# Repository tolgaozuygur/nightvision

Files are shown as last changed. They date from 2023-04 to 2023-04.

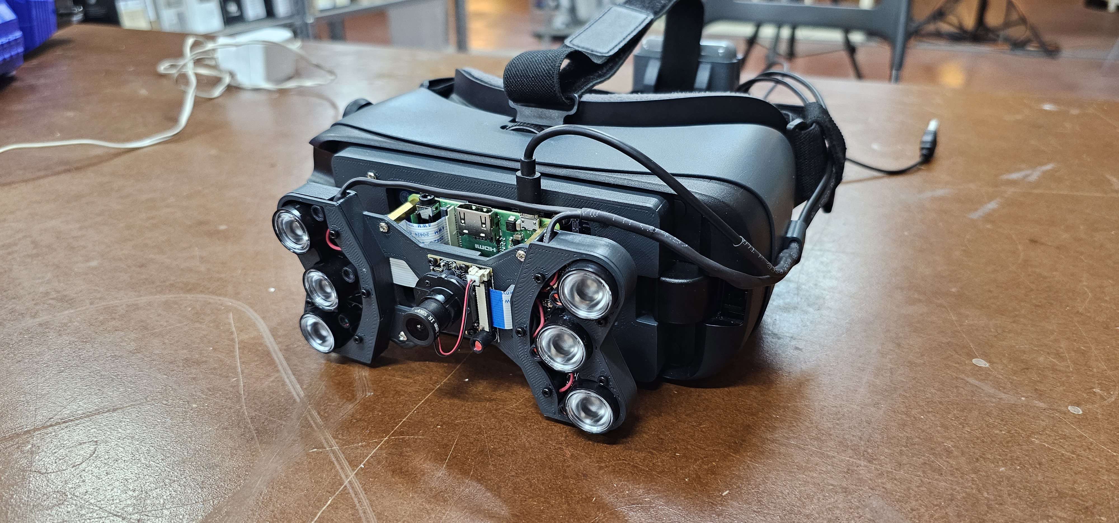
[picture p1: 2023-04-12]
pictures/20230412_170446.jpg

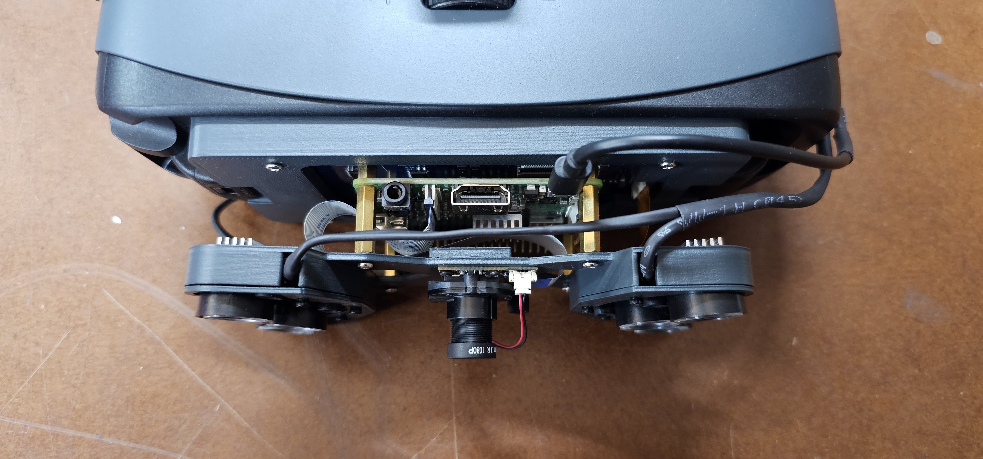
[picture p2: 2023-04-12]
pictures/20230412_170452.jpg

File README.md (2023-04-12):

# Night Vision Goggles
Open source night vision goggles that use old Gear VR headsets as a base. 

## Parts Required / Assembling
- <a href="https://www.raspberrypi.com/products/raspberry-pi-3-model-a-plus/" target="_blank">1x Raspberry Pi 3 A+</a>
- <a href="https://www.waveshare.com/rpi-ir-cut-camera.htm" target="_blank">1x Rpi IR-CUT Camera</a>
- <a href="https://www.waveshare.com/img/devkit/accBoard/Infrared-LED-Board-B/Infrared-LED-Board-B-5.jpg" target="_blank">6x Waveshare IR Led Board</a>
- Samsung Gear VR Headset (You can use any cardboard style headset, but you'll need to modify the 3d files accordingly)
- Powerbank (it should have 2 usb outputs, one should be at least 2A to power the RPI)
- Usb cables, a button switch for function control and RPI shutdown

There are no full instructions yet, but I have added some photos in the /pictures folder to help you assemble the goggles. I also build on my YouTube channel, it is not an instruction video but it might help: https://www.youtube.com/watch?v=c6y9qKiKzgg

## Installation
Copy the nightvision.py to your /pi folder and Run:
``` bash
$ python3 nightvision.py
```
To get it to start when the goggles are booted, follow this guide to add the nightvision.py to LXDE autostart: https://www.raspberrypi-spy.co.uk/2014/05/how-to-autostart-apps-in-rasbian-lxde-desktop/

Note: The script is using MMAL to create multiple images of the camera feed, which is the library for the raspicam. Therefore the script is only tested on Raspberry OS Buster and not Bullseye.

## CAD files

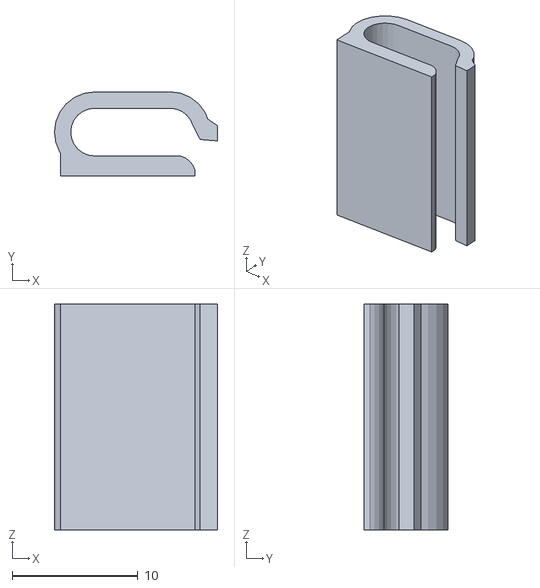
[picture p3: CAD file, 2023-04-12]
3d/nw_cable_clip_x2.stl
13.0 x 6.70 x 18.0

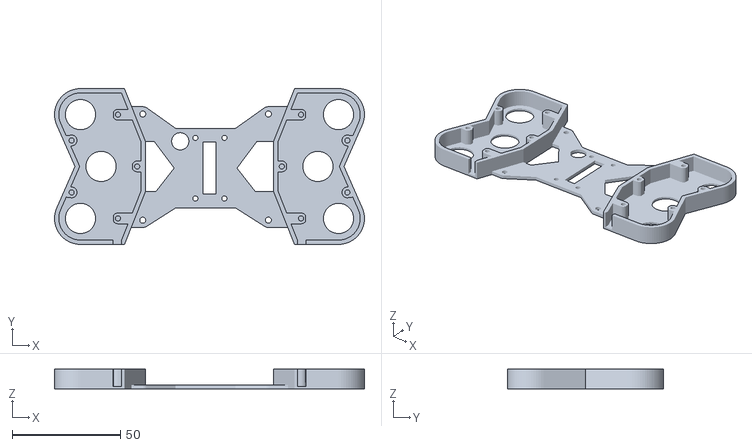
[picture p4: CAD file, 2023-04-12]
3d/nw_cam_holder.stl
143.1 x 72.0 x 9.20

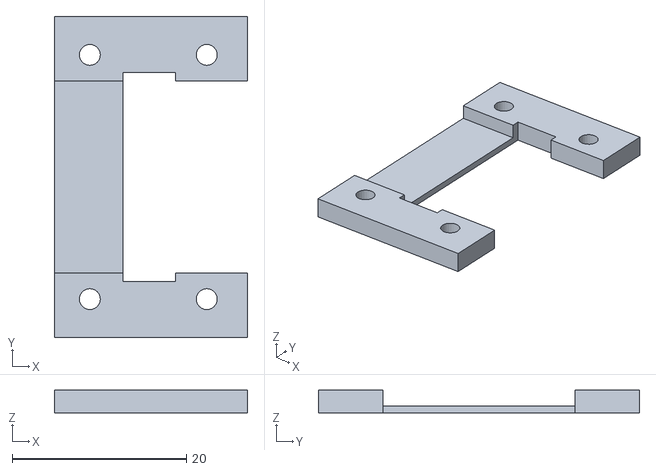
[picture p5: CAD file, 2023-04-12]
3d/nw_cam_ribbon_clip.stl
22.1 x 36.8 x 2.60

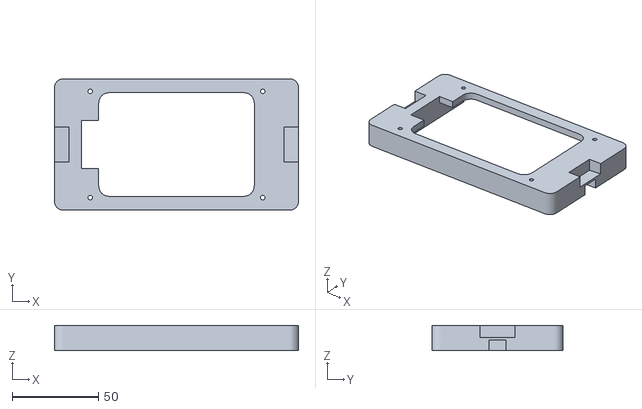
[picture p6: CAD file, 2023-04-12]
3d/nw.stl
141.2 x 76.0 x 14.6

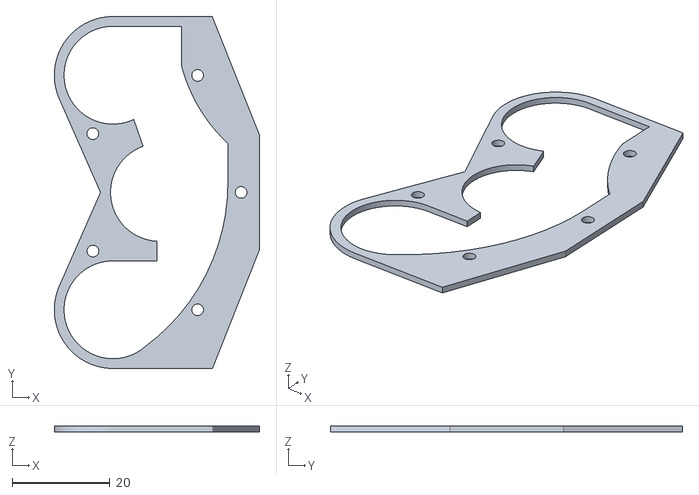
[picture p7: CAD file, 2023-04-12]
3d/nw_led_cap_x2.stl
42.0 x 72.0 x 1.20

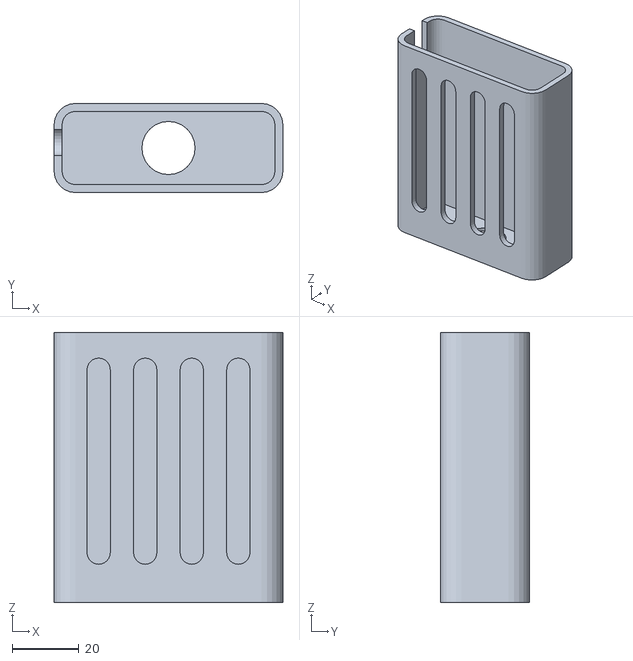
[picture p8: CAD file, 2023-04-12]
3d/nw_battery_case.stl
68.8 x 26.8 x 81.2

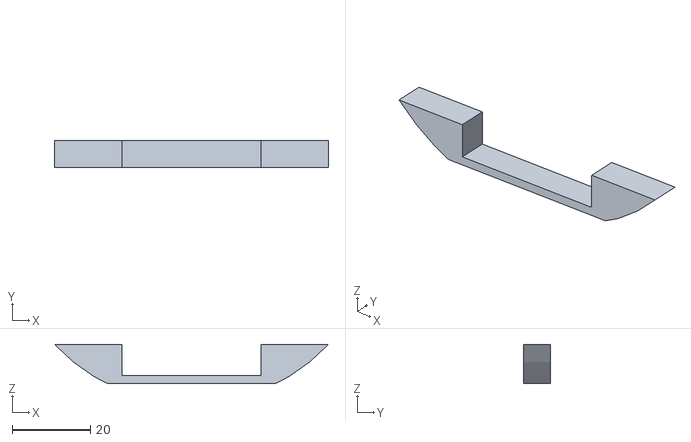
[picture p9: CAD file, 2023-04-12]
3d/nw_battery_case_clip.stl
70.0 x 7.00 x 10.0

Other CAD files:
3d/nw.skp

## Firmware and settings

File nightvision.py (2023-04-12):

from picamera import mmal, mmalobj as mo
from signal import pause
from time import sleep
import sys, pygame, time, os
from gpiozero import Button

#init stuff
SCREEN_WIDTH = 800
SCREEN_HEIGHT = 480
CAM_FPS_LIST = [10,30,60,90]
CAM_WIDTH = 261 #300
CAM_HEIGHT = 348 #400
CAM_ROTATION = 90
CAM_HORIZONTAL_OFFSET = 18
POWER_DOWN_BUTTON_DUR = 5 #seconds

cam_fps_id = 1

#draw black background and fps with pygame
def updateFpsText():
        fps_text = font.render(str(CAM_FPS_LIST[cam_fps_id]) + "fps", True, green, black)
        fps_text_rect = fps_text.get_rect()
        fps_text_rect.center = (CAM_HORIZONTAL_OFFSET-(CAM_WIDTH/2),((SCREEN_HEIGHT+CAM_HEIGHT)/2)+7)
        screen.blit(fps_text, fps_text_rect)
        fps_text_rect.center = (SCREEN_WIDTH-(CAM_HORIZONTAL_OFFSET+(CAM_WIDTH/2)), ((SCREEN_HEIGHT+CAM_HEIGHT)/2)+7)
        screen.blit(fps_text, fps_text_rect)
        pygame.display.flip()

green = (0, 255, 0)
black = (0, 0, 0)
pygame.init()
font = pygame.font.Font(None, 24)
size = width, height = 800, 480
screen = pygame.display.set_mode(size)
screen.fill(black)
pygame.display.toggle_fullscreen()
pygame.mouse.set_visible(False)
pygame.display.update()
updateFpsText()

#use mmal to draw camera preview for each eye
camera = mo.MMALCamera()
splitter = mo.MMALSplitter()
render_l = mo.MMALRenderer()
render_r = mo.MMALRenderer()

camera.outputs[0].framesize = (CAM_WIDTH, CAM_HEIGHT)
camera.outputs[0].framerate = CAM_FPS_LIST[cam_fps_id]
camera.outputs[0].params[mmal.MMAL_PARAMETER_ROTATION] = CAM_ROTATION
camera.outputs[0].commit()

p = render_l.inputs[0].params[mmal.MMAL_PARAMETER_DISPLAYREGION]
p.set = mmal.MMAL_DISPLAY_SET_FULLSCREEN | mmal.MMAL_DISPLAY_SET_DEST_RECT
p.fullscreen = False
p.dest_rect = mmal.MMAL_RECT_T(CAM_HORIZONTAL_OFFSET, (SCREEN_HEIGHT-CAM_HEIGHT)/2, CAM_WIDTH, CAM_HEIGHT)
render_l.inputs[0].params[mmal.MMAL_PARAMETER_DISPLAYREGION] = p
p.dest_rect = mmal.MMAL_RECT_T(SCREEN_WIDTH-(CAM_WIDTH+CAM_HORIZONTAL_OFFSET), (SCREEN_HEIGHT-CAM_HEIGHT)/2, CAM_WIDTH, CAM_HEIGHT)
render_r.inputs[0].params[mmal.MMAL_PARAMETER_DISPLAYREGION] = p

splitter.connect(camera.outputs[0])
splitter.connection.enable()
render_l.connect(splitter.outputs[0])
render_l.connection.enable()
render_r.connect(splitter.outputs[1])
render_r.connection.enable()

#main loop
funcButton = Button(26)
funcButtonDownStartTime = 0
while True:
        if funcButton.is_pressed:
                if funcButtonDownStartTime == 0:
                        funcButtonDownStartTime = time.time()
                else:
                        if (time.time() - funcButtonDownStartTime) >= POWER_DOWN_BUTTON_DUR:
                                os.system("sudo shutdown now -h")
        else:
                if funcButtonDownStartTime != 0:
                        #disable connections
                        splitter.connection.disable()
                        render_l.connection.disable()
                        render_r.connection.disable()
                        #change fps
                        cam_fps_id += 1
                        if cam_fps_id >= len(CAM_FPS_LIST):
                                cam_fps_id = 0
                        print(CAM_FPS_LIST[cam_fps_id])
                        updateFpsText()
                        camera.outputs[0].framerate = CAM_FPS_LIST[cam_fps_id]
                        camera.outputs[0].commit()
                        #enable connections
                        splitter.connection.enable()
                        render_l.connection.enable()
                        render_r.connection.enable()
                        ###
                        print("Func button pressed")
                        funcButtonDownStartTime = 0
        time.sleep(0.1)
